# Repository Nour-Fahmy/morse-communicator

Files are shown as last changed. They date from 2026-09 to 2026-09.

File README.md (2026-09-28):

# Morse Communicator

A two-station embedded messaging prototype built with Arduino Uno boards. Each station lets a user enter Morse code with physical buttons, decodes it into text locally, sends the text over an infrared link, and displays recent messages on a 16 × 2 LCD. The same firmware runs on both stations.

**Project by Nour Waleed and Hagar Ali** · Embedded Systems, May 2026

## How it works

1. Press **DOT** and **DASH** to compose a Morse sequence.
2. Press **END LETTER** to decode a letter or digit; **BACKSPACE** edits input and **SPACE** inserts a word gap.
3. Press **SEND** to transmit the composed text. The firmware sends each character as an NEC IR command and a newline command as the message terminator.
4. The receiving station reconstructs the text, plays an alert, and displays it in its recent chat log. A reply follows the same process in reverse.

The Morse symbols are decoded **before transmission**. The IR link carries text characters, rather than Morse timing pulses.

## Hardware (two stations)

- 2 × Arduino Uno, VS1838B IR receiver, IR LED with a series resistor, 16 × 2 I²C LCD (address `0x27`), and buzzer
- 12 push buttons total (six per station), external pulldown resistors, breadboards, jumpers, and power connections

| Function | Arduino Uno pin |
| --- | --- |
| Dot / dash / end letter | D4 / D5 / D6 |
| Backspace / space / send | D7 / D8 / D9 |
| Buzzer / IR transmitter / IR receiver | D10 / D3 / D11 |
| LCD SDA / SCL | A4 / A5 |

The sketch uses `INPUT` for the buttons, so the documented **external pulldown resistors are required** for stable readings.

## Build and run

1. Install the Arduino IDE and the `IRremote` and `LiquidCrystal_I2C` libraries. `Wire` ships with the Arduino core. Library versions were not supplied with the project.
2. Open [`firmware/MorseArduinoCode.ino`](firmware/MorseArduinoCode.ino) in the Arduino IDE and select an Arduino Uno.
3. Wire each station using the pin map above and the project documentation. Check the IR LED polarity and its current-limiting resistor.
4. Upload the same sketch to both boards. Point the IR transmitter of each station toward the other station's receiver.

## Project files

| File | Contents |
| --- | --- |
| [`firmware/MorseArduinoCode.ino`](firmware/MorseArduinoCode.ino) | Arduino firmware, Morse lookup, buttons, LCD, audio, and NEC IR handling |
| [`hardware/Our-Morse.brd`](hardware/Our-Morse.brd) | Autodesk EAGLE board layout supplied with the project |
| [`docs/Project-Documentation.docx`](docs/Project-Documentation.docx) | Hardware, architecture, test notes, and limitations |
| [`docs/Project-Presentation.pptx`](docs/Project-Presentation.pptx) | Project presentation |

The documentation reports successful two-way exchanges and button/LCD validation on physical hardware. This repository packages the supplied work; I did not independently compile or test it on the boards.

## Limits

- Infrared requires alignment and a clear line of sight.
- The LCD displays two rows; the sketch retains six chat entries in memory but shows only the two newest in receive mode.
- Morse input supports A–Z and 0–9. Punctuation is not part of the lookup table.
- Dynamic `String` usage and chat history consume limited Uno RAM; long messages have no explicit length bound.

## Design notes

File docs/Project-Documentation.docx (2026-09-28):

Morse Communicator Project

Bidirectional Infrared Morse Messaging Terminal

Embedded Systems Project Documentation

Prepared By: Nour Waleed, Hagar Ali

Course / Subject: Embedded Systems

Instructor: Dr. Alaa Hamdi

Date: 2026-05-10

# 1. Project Overview

This project implements a two-way Morse communication system using two Arduino-based terminals. Each terminal allows the user to compose English text through dedicated Morse buttons, transmit the message through an infrared link, receive a reply from the opposite side, and maintain a lightweight chat history on a 16x2 I2C LCD.

# 2. Objectives

- Build a working bidirectional embedded communication system using two identical stations.
- Convert Morse button input into readable English text before transmission.
- Transmit data over IR and reconstruct it on the receiver side.
- Allow both sides to send, receive, and reply using the same firmware.
- Display the latest chat history on the LCD for demonstration and validation.

# 3. System Overview

The user does not type letters directly. Instead, each letter is entered in Morse code using six control buttons. The current Morse sequence is decoded locally into an English character when END LETTER is pressed. The system then stores the full message, sends it over IR character by character, detects the end-of-message marker, and displays sent and received lines as chat history.

# 4. Hardware Components

- 2 × Arduino Uno boards
- 2 × VS1838B IR receiver modules
- 2 × IR LEDs with series resistors for transmission
- 2 × 16x2 I2C LCD modules (address 0x27)
- 2 × buzzers for feedback
- 12 × push buttons (6 per station)
- Pulldown resistors for button inputs
- Breadboards, jumper wires, and power connections

# 5. Pin Mapping

Signal | Arduino Pin
DOT button | D4
DASH button | D5
END LETTER button | D6
BACKSPACE button | D7
SPACE button | D8
SEND button | D9
Buzzer | D10
IR TX | D3
IR RX | D11
LCD SDA | A4
LCD SCL | A5

# 6. Button Functions

Button | Function | Description
DOT | Appends . | Adds one dot to the current Morse sequence.
DASH | Appends - | Adds one dash to the current Morse sequence.
END LETTER | Decode current code | Converts the current Morse sequence into one English character.
BACKSPACE | Edit current input | Deletes the last Morse symbol or the last text character.
SPACE | Insert space | Closes the current letter if valid, then inserts a word gap.
SEND | Transmit message | Sends the composed text over IR and returns the station to receive mode.

# 7. Software Architecture

The sketch is structured into small functional blocks so the same firmware can run on both stations.

- Pin definitions and hardware initialization
- Morse lookup table and local Morse decoding
- Button scanning and one-shot press handling
- LCD rendering for send mode and receive mode
- IR transmission routine
- IR reception and message reconstruction
- Chat history storage and display update

# 8. Code Pipeline

The execution pipeline of the final code is shown below:

1. setup() initializes pins, LCD, buzzer, IR sender, and IR receiver.

2. loop() continuously calls checkButtons() and checkReceive().

3. checkButtons() detects a new valid press and calls handleButton(index).

4. handleButton() updates the Morse sequence, composed text, or sends the message depending on the pressed button.

5. sendMessageIR() transmits the outgoing string character by character and appends an end-of-message marker.

6. checkReceive() reconstructs incoming characters until the end marker is received.

7. addToLog() stores both sent and received lines in chat history.

8. updateLCD() refreshes the visible state of the system on the LCD.

# 9. Main Functions and Their Roles

Function | Role | Notes
setup() | Initializes all peripherals and displays startup state. | Runs once on power-up.
loop() | Main program loop. | Continuously checks buttons and incoming IR data.
checkButtons() | Scans button states with debounce and one-shot handling. | Prevents repeated triggers while button stays pressed.
handleButton(index) | Processes the action of each button. | Updates Morse, message, send, delete, or space operations.
decodeMorse(code) | Converts Morse symbols into one English character. | Returns null if the code is invalid.
sendMessageIR(msg) | Sends a message over the IR transmitter. | Transmits each character and then a terminator.
checkReceive() | Reads IR packets and rebuilds incoming messages. | Adds completed incoming message to history.
addToLog(msg) | Stores sent and received chat lines. | Keeps the latest conversation entries.
updateLCD() | Refreshes the LCD display. | Shows compose mode or latest chat history depending on state.

## Representative Function Calls

setup() -> lcd.init() -> IrSender.begin(IR_TX_PIN) -> IrReceiver.begin(IR_RX_PIN, DISABLE_LED_FEEDBACK)

loop() -> checkButtons() -> handleButton(index)

loop() -> checkReceive() -> addToLog("<<" + receivedMessage) -> updateLCD()

handleButton(SEND) -> sendMessageIR(composedMessage) -> addToLog(">>" + composedMessage)

# 10. Simulation Section

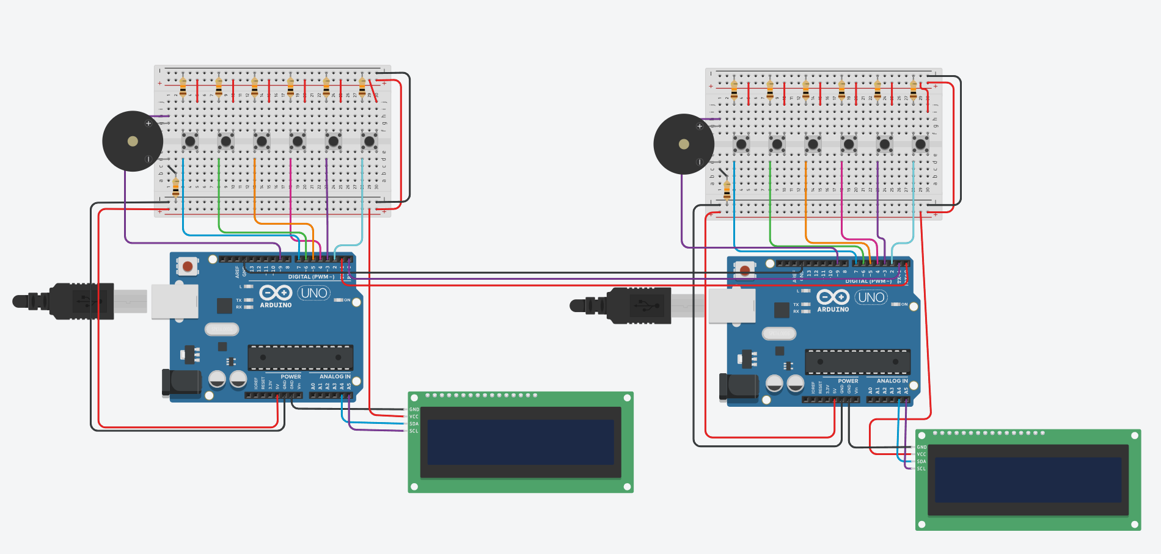
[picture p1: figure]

# 11. Difference Between Simulation and Hardware Implementation

Aspect | Simulation | Hardware Implementation
Execution environment | Runs in Wokwi or software-only environment. | Runs on two real Arduino boards with actual sensors and emitters.
Communication medium | Often simplified or emulated. | Uses a real infrared LED and a real IR receiver with line-of-sight constraints.
Debugging | Fast to iterate, easy to rewire, and easy to inspect visually. | Requires physical wiring checks, alignment checks, and component-level troubleshooting.
Timing behavior | Usually more controlled and predictable. | Affected by blocking code, IR timing, ambient light, and hardware tolerances.
Hardware faults | No loose wires or reversed components unless modeled. | Real issues include wrong polarity, bad rows, weak transmission, and receiver saturation.
Validation value | Good for logic verification and UI flow. | Good for proving the full embedded system works in real conditions.

# 12. Testing and Validation

- Verified button operation for all six controls.
- Verified buzzer feedback and LCD updates.
- Verified one-way IR transmission.
- Verified reply transmission in the opposite direction.
- Verified repeated exchanges after fixing button and receive-state issues.
- Verified chat history update for both sent and received messages.

# 13. Issues Faced and Applied Fixes

Issue | Impact | Applied Fix
Button mapping and breadboard row confusion | Buttons triggered the wrong actions or stayed active continuously. | Rebuilt the button area and aligned each signal path with its intended pin.
Buzzer activated without pressing buttons | Made debugging impossible and indicated a short or wrong row usage. | Isolated the buzzer into a clean two-row connection.
IR protocol mismatch | One side sent but the other side did not rebuild characters correctly. | Matched transmit and receive handling to the same NEC command-byte workflow.
Reply path instability | The first exchange worked, but later replies failed. | Reduced blocking behavior and re-armed the receiver after sending.
History too limited | Only a minimal or incomplete conversation state was visible. | Added a larger chat history and logged both sent and received messages.

# 14. Limitations

- The 16x2 LCD can only display two lines at a time, so history is stored but not fully visible at once.
- IR communication still depends on distance, alignment, and line of sight.
- History depth is limited by available Arduino RAM.
- The system currently targets letters and digits only; punctuation support is limited.

# 15. Conclusion

The Morse Communicator project successfully demonstrates a complete embedded communication workflow: button-based Morse input, local English decoding, infrared transmission, message reception, reply handling, and chat-style history display. The final system is symmetrical, practical for demonstration, and strong enough to represent a complete embedded systems project.

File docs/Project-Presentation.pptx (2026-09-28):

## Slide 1

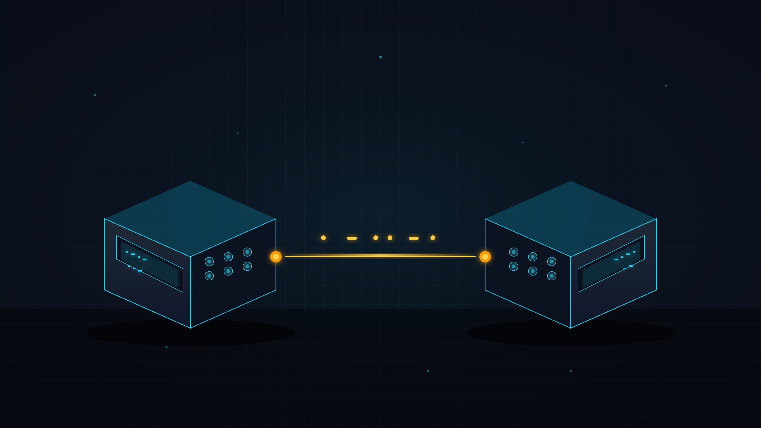
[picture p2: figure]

EMBEDDED SYSTEMS · PROJECT BRIEF · 2026

MORSE

COMMUNICATOR

Bidirectional Infrared Morse Messaging Terminal

> SYSTEM ONLINE · AWAITING SIGNAL

PREPARED BY
Nour Waleed · Hagar Ali
INSTRUCTOR
Dr. Alaa Hamdi

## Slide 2

00 · TABLE OF CONTENTS

What we'll cover.

Eight chapters from concept to working prototype.

Overview

What the system does

01

Objectives

What we set out to build

02

Hardware

Components & pin map

Button Layer

Input mechanics

03

04

Software

Code architecture

05

Pipeline

End-to-end data flow

06

Sim vs HW

Where they diverge

● INDEX · 08 CHAPTERS

07

Issues Fixed

Real-world debugging

08

02 / 12

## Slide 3

01 · PROJECT OVERVIEW

Two-way Morse, over light.

01 THE SETUP

Two identical Arduino terminals. Each can send and receive Morse-encoded text through an infrared link.

02 THE INTERACTION

Six dedicated buttons compose letters. The system decodes Morse locally, transmits the message, and shows the chat on a 16×2 LCD.

2

STATIONS

6

BUTTONS / SIDE

36

MORSE GLYPHS

▸ CLICK TO REVEAL

03 / 12

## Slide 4

02 · OBJECTIVES

Five goals.

Every objective is verifiable on the hardware.

01

BUILD

Bidirectional embedded comms with two identical stations.

02

CONVERT

Morse button input → readable English text before transmission.

03

TRANSMIT

Send data over IR; reconstruct it accurately on the receiver.

04

RESPOND

Same firmware handles both send and reply on either side.

05

DISPLAY

Show latest chat history on the LCD for live demo + validation.

● OBJECTIVES · 5 VERIFIED

▸ CLICK TO REVEAL

04 / 12

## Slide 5

03 · HARDWARE

Bill of materials.

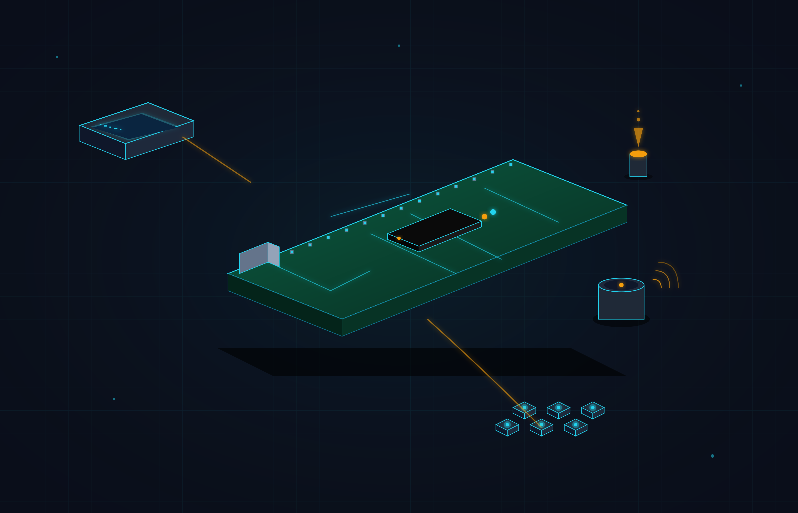
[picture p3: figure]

Arduino Uno

Main controllers

2×

VS1838B

IR receiver

2×

IR LED

Emitter + resistor

2×

16×2 LCD

I²C @ 0x27

2×

Buzzer

Tone feedback

PIN MAP

2×

Push Button

6 per station

12×

DOT
D4

DASH
D5

END
D6

BACK
D7

SPACE
D8

SEND
D9

BUZZ
D10

IR TX
D3

IR RX
D11

SDA
A4

SCL
A5

▸ CLICK TO REVEAL

05 / 12

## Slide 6

04 · BUTTON LAYER

Six buttons. One language.

No keyboard. No screen typing. Pure Morse composition.

DOT

Append a dot

PIN D4

DASH

Append a dash

PIN D5

—

END

Decode → letter

PIN D6

↵

BACK

Edit current

PIN D7

SPACE

Word gap

PIN D8

▸ CLICK TO REVEAL

SEND

Transmit via IR

PIN D9

⌫

␣

▶

● INPUT INTERFACE · 6 BTN

06 / 12

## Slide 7

05 · SOFTWARE ARCHITECTURE

Modular firmware.

One sketch runs on both stations — symmetric design.

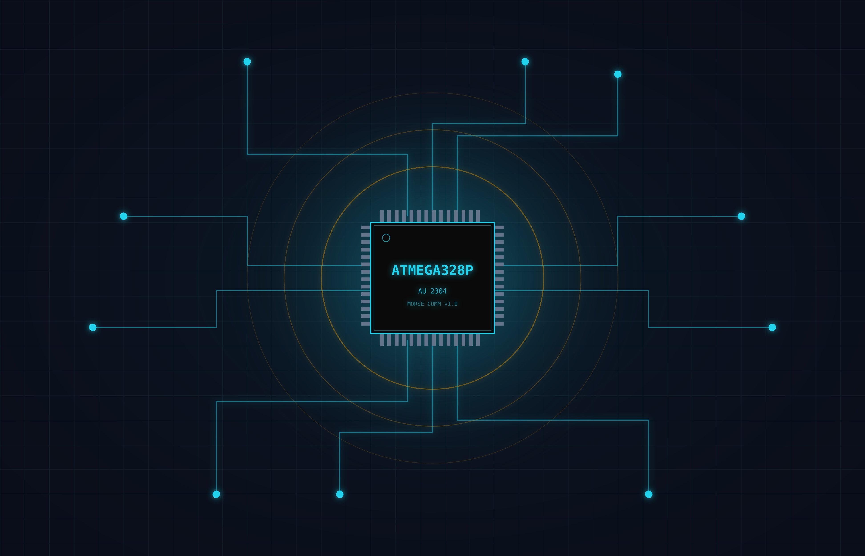
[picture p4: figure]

Init pins, LCD, buzzer, IR.

setup()

Continuous: buttons + receive.

Debounced, one-shot detection.

loop()

Action dispatch by button.

checkButtons()

handleButton(i)

Code → English char (or null).

decodeMorse()

Char-by-char NEC transmission.

sendMessageIR()

Rebuild incoming → end marker.

checkReceive()

Render send mode or chat log.

updateLCD()

▸ CLICK TO REVEAL

07 / 12

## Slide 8

06 · EXECUTION PIPELINE

Eight stages, one beat.

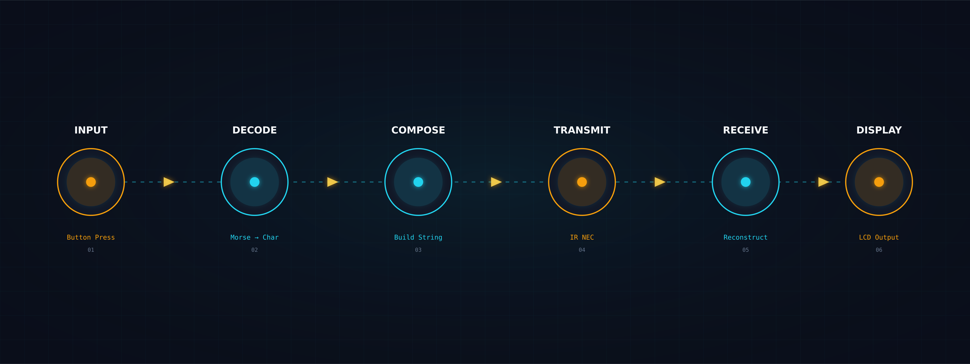
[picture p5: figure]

From button press to chat history — the message journey.

01

setup()

Boot peripherals

02

loop()

Poll buttons + IR

03

handleButton()

Compose / send

04

sendMessageIR()

Transmit + EOM

05

checkReceive()

Rebuild chars

06

addToLog()

Store in history

● DATA FLOW · 6 STAGES

▸ CLICK TO REVEAL

08 / 12

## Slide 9

07 · SIMULATION vs HARDWARE

Two worlds. Same logic.

What works in Tikercad doesn't always survive the breadboard.

ASPECT

ENVIRONMENT

SIMULATION

Tinkercad

HARDWARE

Two real Arduino boards

MEDIUM

UART

Physical IR LED + receiver

DEBUGGING

Fast iteration, easy rewiring

Wiring checks + alignment

TIMING

Predictable, controlled

Affected by ambient light + blocking code

FAULTS

Only what's modeled

Polarity, weak TX, saturation

VALUE

Verifies logic & UI flow

▸ CLICK TO REVEAL

Proves the full embedded system

09 / 12

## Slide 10

08 · ISSUES & FIXES

What broke. What we did.

Real debugging — every fix is wired into the final code.

Rebuilt button area, aligned signal paths.

BUTTON CONFUSION

Triggered wrong actions, stayed active.

→

→

→

→

→

APPLIED FIX

Isolated buzzer to clean two-row connection.

BUZZER GHOST FIRES

APPLIED FIX

Unified to NEC command-byte workflow.

Activated without input — short or wrong row.

IR PROTOCOL MISMATCH

APPLIED FIX

TX sent but RX couldn't rebuild chars.

Reduced blocking; re-armed receiver after TX.

REPLY PATH INSTABLE

First exchange worked, later replies failed.

APPLIED FIX

Larger log; both sent + received tracked.

● 5 ISSUES · 5 RESOLVED

▸ CLICK TO REVEAL

HISTORY TOO SHALLOW

APPLIED FIX

Only minimal chat state visible.

10 / 12

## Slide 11

09 · TESTING · VALIDATION · LIMITS

It works. Here's how we know.

✓ VERIFIED ON HARDWARE

All six controls respond correctly

Buzzer feedback + LCD updates

One-way IR transmission

Reply transmission (reverse direction)

Repeated exchanges after fixes

Chat history logs both sides

△ KNOWN LIMITATIONS

16×2 LCD shows only two lines at once

IR depends on distance + alignment

History depth bounded by Arduino RAM

Letters + digits only (limited punctuation)

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
▸ CLICK TO REVEAL

11 / 12

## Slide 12

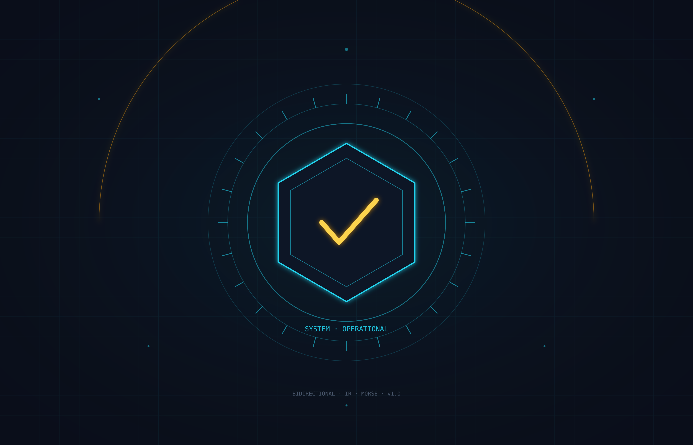
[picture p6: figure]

▸ CONCLUSION · PROJECT COMPLETE

Signal sent.

Signal received.

The Morse Communicator delivers a complete embedded workflow: button-based Morse input, local English decoding, infrared transmission, reception, reply, and chat-style history — symmetric across two stations.

// MORSE COMMUNICATOR · v1.0 · EMBEDDED SYSTEMS · 2026

100%

OBJECTIVES MET

ISSUES RESOLVED

5/5

STATIONS · 1 PROTOCOL

2

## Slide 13

EMBEDDED SYSTEMS · PROJECT BRIEF · Bidirectional Infrared Morse Messaging Terminal

Thank

> SYSTEM OFFLINE · THAT’S IT

YOU

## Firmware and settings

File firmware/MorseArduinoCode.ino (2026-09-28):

#include <Wire.h>
#include <LiquidCrystal_I2C.h>
#include <IRremote.hpp>


// ── Pin Definitions ──────────────────────────────────────────────
#define BTN_DOT        4
#define BTN_DASH       5
#define BTN_END_LETTER 6
#define BTN_BACK       7
#define BTN_SPACE      8
#define BTN_SEND       9

#define BUZZER_PIN     10
#define IR_TX_PIN      3
#define IR_RX_PIN      11

// ── Tone Frequencies ─────────────────────────────────────────────
#define TONE_DOT         1000
#define TONE_DASH         700
#define TONE_END_LETTER  1400
#define TONE_BACK         500
#define TONE_SEND        1800
#define TONE_SPACE       1200
#define TONE_ERROR        250
#define TONE_RECEIVE     1500
#define TONE_DURATION      80

// ── Modes ────────────────────────────────────────────────────────
#define MODE_RECEIVE 0
#define MODE_SEND    1
int currentMode = MODE_RECEIVE;

// ── LCD ──────────────────────────────────────────────────────────
LiquidCrystal_I2C lcd(0x27, 16, 2);

// ── Morse Table ──────────────────────────────────────────────────
struct MorseEntry {
  char letter;
  const char* code;
};

const MorseEntry morseTable[] = {
  {'A', ".-"},   {'B', "-..."}, {'C', "-.-."}, {'D', "-.."},
  {'E', "."},    {'F', "..-."}, {'G', "--."},  {'H', "...."},
  {'I', ".."},   {'J', ".---"}, {'K', "-.-"},  {'L', ".-.."},
  {'M', "--"},   {'N', "-."},   {'O', "---"},  {'P', ".--."},
  {'Q', "--.-"}, {'R', ".-."},  {'S', "..."},  {'T', "-"},
  {'U', "..-"},  {'V', "...-"}, {'W', ".--"},  {'X', "-..-"},
  {'Y', "-.--"}, {'Z', "--.."},
  {'0', "-----"},{'1', ".----"},{'2', "..---"},{'3', "...--"},
  {'4', "....-"},{'5', "....."},{'6', "-...."},{'7', "--..."},
  {'8', "---.."},{'9', "----."}
};
const int MORSE_TABLE_SIZE = sizeof(morseTable) / sizeof(MorseEntry);

// ── State ────────────────────────────────────────────────────────
String currentMorse    = "";
String composedMessage = "";
String receivedMessage = "";

// chat history
const int CHAT_HISTORY_SIZE = 6;
String chatLog[CHAT_HISTORY_SIZE];

// ── Buttons ──────────────────────────────────────────────────────
const int buttonPins[6] = {
  BTN_DOT, BTN_DASH, BTN_END_LETTER, BTN_BACK, BTN_SPACE, BTN_SEND
};

bool lastStableState[6] = {LOW, LOW, LOW, LOW, LOW, LOW};
unsigned long lastChangeTime[6] = {0, 0, 0, 0, 0, 0};
bool pressHandled[6] = {false, false, false, false, false, false};

const unsigned long DEBOUNCE_MS = 35;

// ── Audio Helpers ────────────────────────────────────────────────
void playToneSimple(int freq, int duration) {
  tone(BUZZER_PIN, freq, duration);
}

void playError() {
  tone(BUZZER_PIN, TONE_ERROR, 120);
}

void playReceiveChime() {
  tone(BUZZER_PIN, TONE_RECEIVE, 100);
}

// ── Morse Decode ─────────────────────────────────────────────────
char decodeMorse(const String& code) {
  for (int i = 0; i < MORSE_TABLE_SIZE; i++) {
    if (code == morseTable[i].code) {
      return morseTable[i].letter;
    }
  }
  return '\0';
}

// ── Chat Log ─────────────────────────────────────────────────────
void addToLog(const String& msg) {
  for (int i = CHAT_HISTORY_SIZE - 1; i > 0; i--) {
    chatLog[i] = chatLog[i - 1];
  }
  chatLog[0] = msg;
}

// ── LCD Update ───────────────────────────────────────────────────
void updateLCD() {
  lcd.clear();

  if (currentMode == MODE_SEND) {
    lcd.setCursor(0, 0);
    String row0 = "TX:";
    row0 += (currentMorse.length() == 0) ? "---" : currentMorse;
    if (row0.length() > 16) row0 = row0.substring(row0.length() - 16);
    lcd.print(row0);

    lcd.setCursor(0, 1);
    String row1 = composedMessage;
    if (row1.length() > 16) row1 = row1.substring(row1.length() - 16);
    lcd.print(row1);
  } else {
    lcd.setCursor(0, 0);
    String row0 = (chatLog[0].length() == 0) ? "Listening..." : chatLog[0];
    if (row0.length() > 16) row0 = row0.substring(row0.length() - 16);
    lcd.print(row0);

    lcd.setCursor(0, 1);
    String row1 = (chatLog[1].length() == 0) ? "" : chatLog[1];
    if (row1.length() > 16) row1 = row1.substring(row1.length() - 16);
    lcd.print(row1);
  }
}

// ── IR Send ──────────────────────────────────────────────────────
void sendMessageIR(const String& msg) {
  const uint16_t address = 0x00;

  for (int i = 0; i < msg.length(); i++) {
    uint8_t command = (uint8_t)msg[i];
    IrSender.sendNEC(address, command, 0);
    delay(120);
  }

  // newline as end marker
  IrSender.sendNEC(address, '\n', 0);
  delay(150);

  // re-arm receiver after sending
  IrReceiver.begin(IR_RX_PIN, DISABLE_LED_FEEDBACK);
}

// ── IR Receive ───────────────────────────────────────────────────
void checkReceive() {
  if (currentMode != MODE_RECEIVE) return;

  if (IrReceiver.decode()) {
    uint8_t cmd = IrReceiver.decodedIRData.command;
    IrReceiver.resume();

    if (cmd == '\n') {
      if (receivedMessage.length() > 0) {
        playReceiveChime();
        addToLog("<<" + receivedMessage);
        receivedMessage = "";
        currentMode = MODE_RECEIVE;
        updateLCD();
      }
      return;
    }

    if (cmd >= 32 && cmd <= 126) {
      receivedMessage += (char)cmd;
      updateLCD();
    }
  }
}

// ── Button Action Handler ────────────────────────────────────────
void handleButton(int index) {
  if (currentMode == MODE_RECEIVE) {
    currentMode = MODE_SEND;
    currentMorse = "";
    composedMessage = "";
    updateLCD();
  }

  switch (index) {
    case 0: // DOT
      currentMorse += ".";
      playToneSimple(TONE_DOT, TONE_DURATION);
      updateLCD();
      break;

    case 1: // DASH
      currentMorse += "-";
      playToneSimple(TONE_DASH, TONE_DURATION);
      updateLCD();
      break;

    case 2: // END LETTER
      if (currentMorse.length() == 0) {
        playError();
        break;
      } else {
        char decoded = decodeMorse(currentMorse);
        if (decoded == '\0') {
          playError();
          currentMorse = "";
          updateLCD();
        } else {
          composedMessage += decoded;
          currentMorse = "";
          playToneSimple(TONE_END_LETTER, TONE_DURATION);
          updateLCD();
        }
      }
      break;

    case 3: // BACKSPACE
      playToneSimple(TONE_BACK, TONE_DURATION);
      if (currentMorse.length() > 0) {
        currentMorse.remove(currentMorse.length() - 1);
      } else if (composedMessage.length() > 0) {
        composedMessage.remove(composedMessage.length() - 1);
      }
      updateLCD();
      break;

    case 4: // SPACE
      if (currentMorse.length() > 0) {
        char decoded = decodeMorse(currentMorse);
        if (decoded != '\0') {
          composedMessage += decoded;
        }
        currentMorse = "";
      }
      composedMessage += ' ';
      playToneSimple(TONE_SPACE, TONE_DURATION);
      updateLCD();
      break;

    case 5: // SEND
      if (composedMessage.length() == 0) {
        playError();
        break;
      }

      playToneSimple(TONE_SEND, TONE_DURATION * 2);

      lcd.clear();
      lcd.setCursor(0, 0);
      lcd.print(">> SENDING:");
      lcd.setCursor(0, 1);
      {
        String display = composedMessage;
        if (display.length() > 16) display = display.substring(display.length() - 16);
        lcd.print(display);
      }

      sendMessageIR(composedMessage);
      addToLog(">>" + composedMessage);

      composedMessage = "";
      currentMorse = "";
      currentMode = MODE_RECEIVE;
      updateLCD();
      break;
  }
}

// ── Button Scan ──────────────────────────────────────────────────
void checkButtons() {
  for (int i = 0; i < 6; i++) {
    bool reading = digitalRead(buttonPins[i]);

    if (reading != lastStableState[i]) {
      lastChangeTime[i] = millis();
      lastStableState[i] = reading;
    }

    if ((millis() - lastChangeTime[i]) > DEBOUNCE_MS) {
      if (reading == HIGH) {
        if (!pressHandled[i]) {
          handleButton(i);
          pressHandled[i] = true;
        }
      } else {
        pressHandled[i] = false;
      }
    }
  }
}

// ── Setup ────────────────────────────────────────────────────────
void setup() {
  Serial.begin(9600);

  for (int i = 0; i < 6; i++) {
    pinMode(buttonPins[i], INPUT); 
  }

  pinMode(BUZZER_PIN, OUTPUT);

  for (int i = 0; i < CHAT_HISTORY_SIZE; i++) {
    chatLog[i] = "";
  }

  lcd.init();
  lcd.backlight();
  lcd.clear();
  lcd.setCursor(0, 0);
  lcd.print("Morse Comm HW");
  lcd.setCursor(0, 1);
  lcd.print("Listening...");

  IrSender.begin(IR_TX_PIN);
  IrReceiver.begin(IR_RX_PIN, DISABLE_LED_FEEDBACK);

  delay(1000);
  updateLCD();
}

// ── Loop ─────────────────────────────────────────────────────────
void loop() {
  checkButtons();
  checkReceive();
}
